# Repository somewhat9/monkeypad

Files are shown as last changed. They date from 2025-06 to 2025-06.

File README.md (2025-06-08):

# Monkeypad
Monkeypad is a macropad with 9 switches, an OLED screen and a rotary encoder.

*Completely designed by [@somewhat9](github.com/somewhat9).*  
  
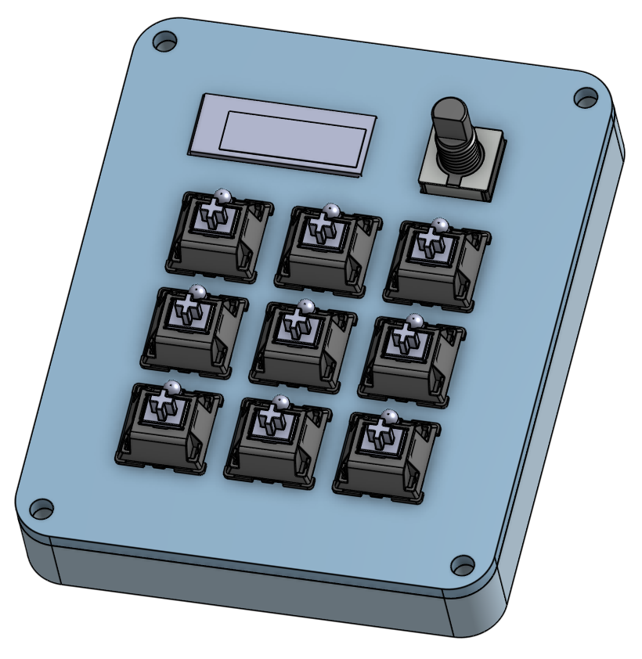
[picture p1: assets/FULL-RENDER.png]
Monkeypad


## Features:
- 128x32 OLED Display
- EC11 Rotary Encoder
- 9 Keys
- 3D Printed Case
- QMK Firmware

### Schematic
Used [KiCAD](https://www.kicad.org/), an open source EDA software, to create the schematic and design the PCB.  

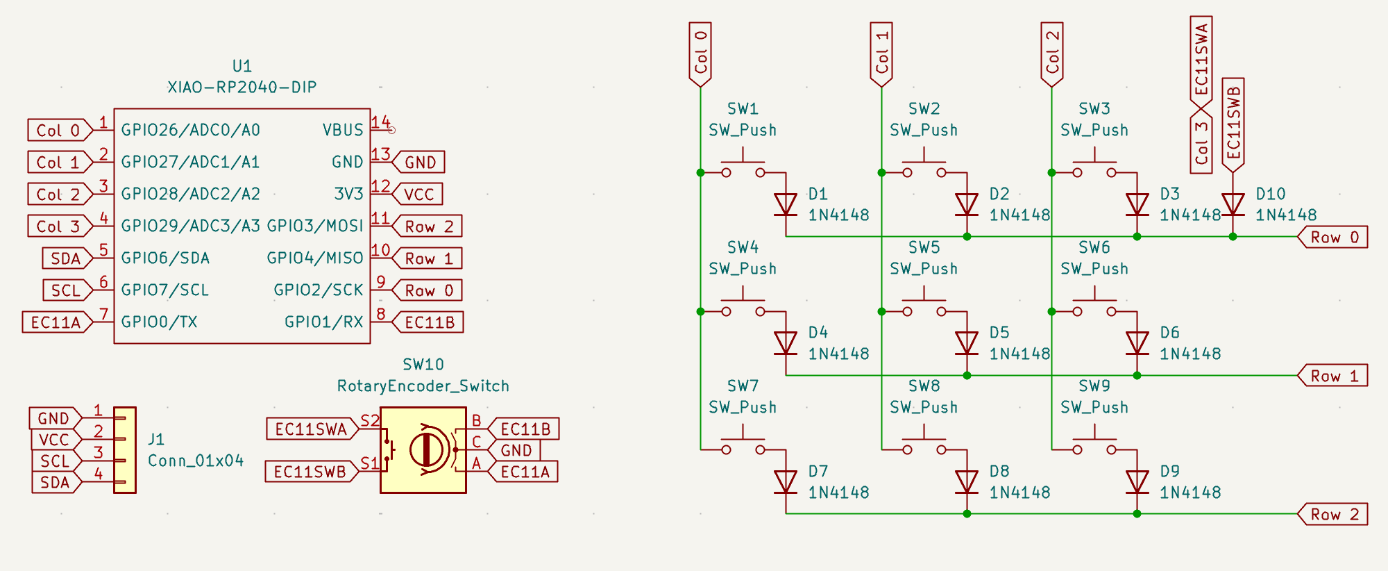
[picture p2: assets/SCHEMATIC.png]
Schematic


### PCB
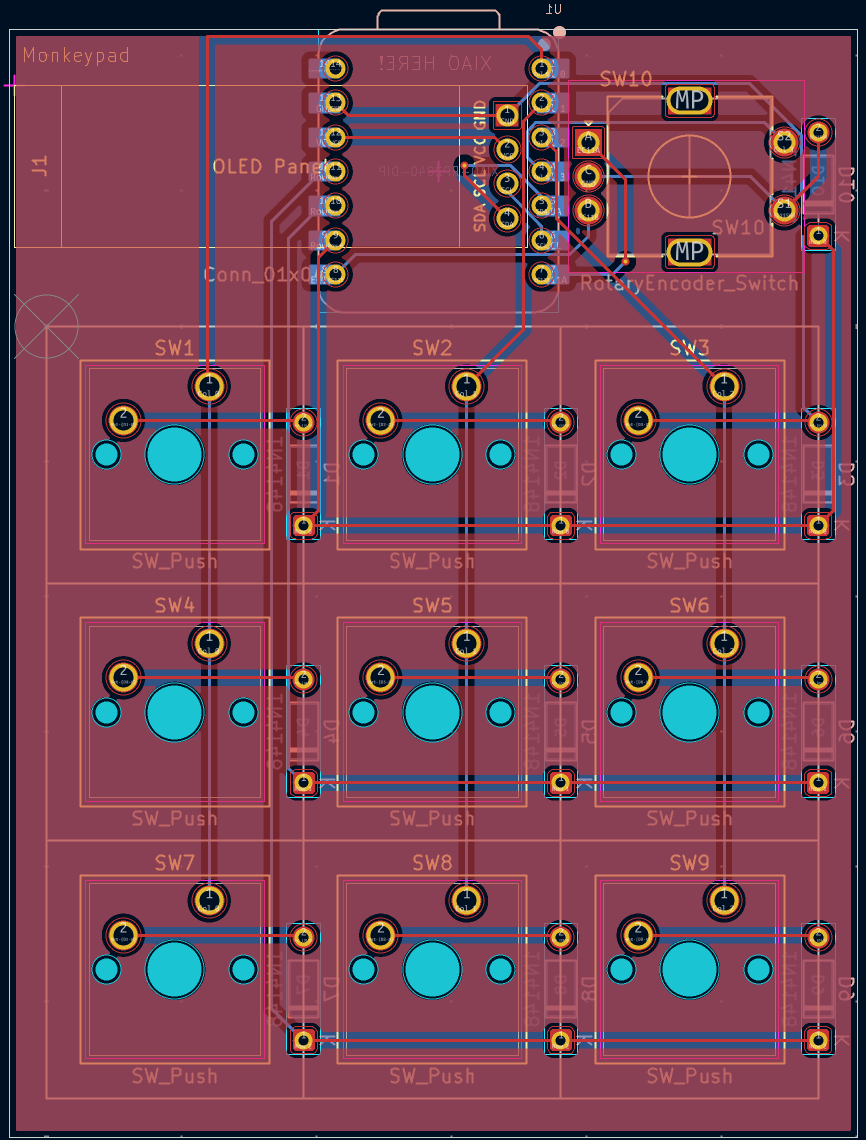
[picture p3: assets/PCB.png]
PCB


### Case
Utilized [Onshape](https://www.onshape.com/en/), a 3D modeling CAD software, to design the 3D models for the case.  

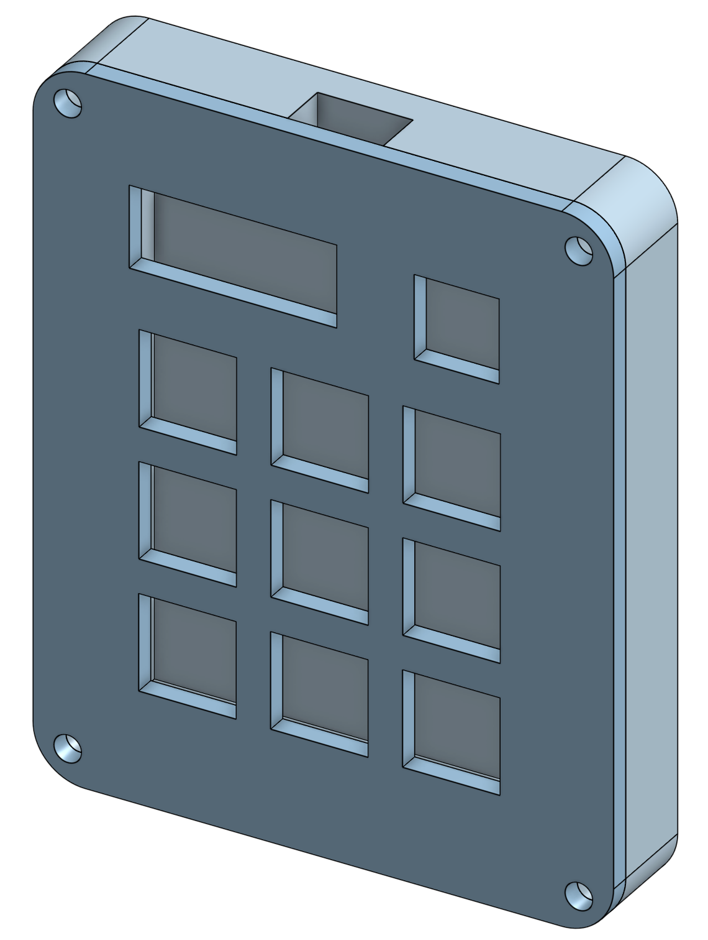
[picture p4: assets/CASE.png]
Case


### Firmware
The firmware for this macropad was built using the [QMK](https://qmk.fm/) project.
The open-source repository can be found [here](https://github.com/qmk/qmk_firmware).

## BOM:
- 9x Cherry MX Switches
- 1x EC11 Rotary Encoder
- 1x 128x32 OLED Display
- 1x XIAO RP2040
- 9x Blank DSA Keycaps (White)
- 4x M3x16mm Screws
- 4x M3x5mx4mm Heatset Inserts
- 1x 3D Printed Case

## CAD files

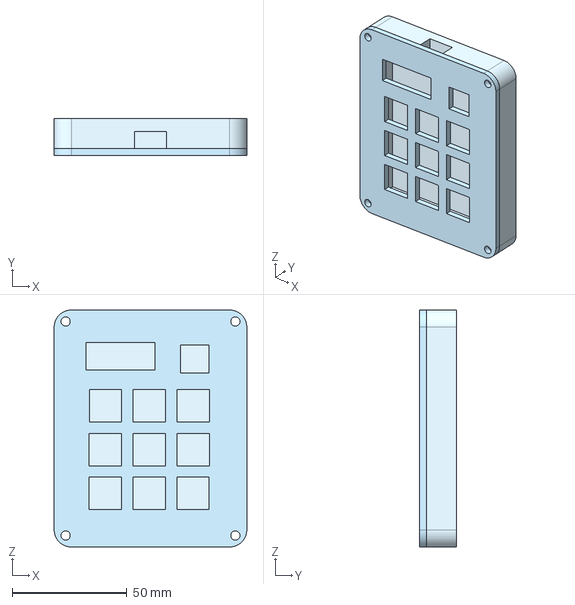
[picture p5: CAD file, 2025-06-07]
cad/monkeypad.step
83.8 x 16.0 x 103.1 mm

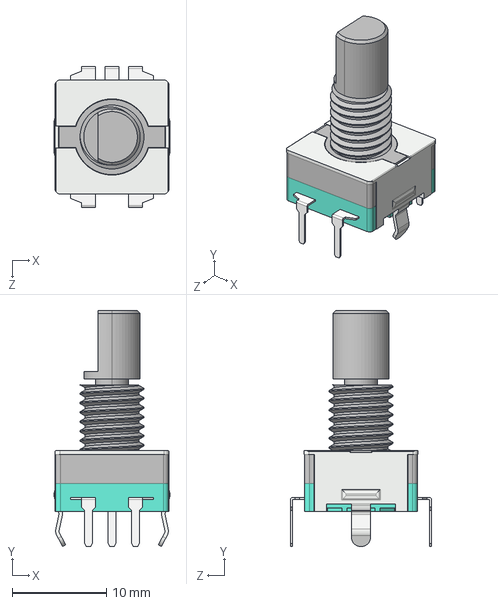
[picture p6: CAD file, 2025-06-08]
pcb/models/ENCODER.step
12.3 x 25.1 x 15.0 mm

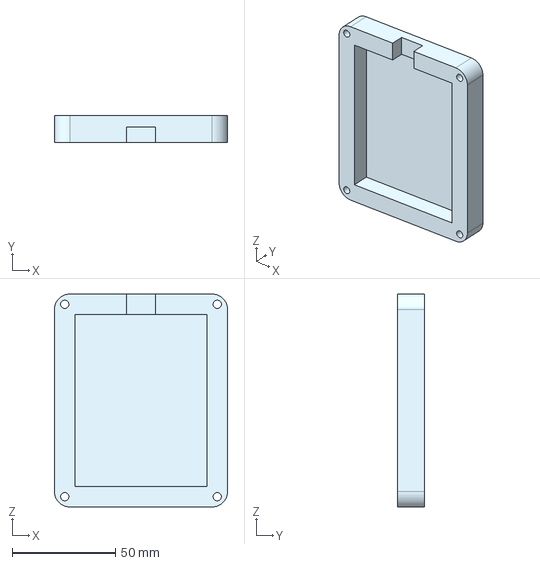
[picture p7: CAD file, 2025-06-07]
production/base.step
83.8 x 13.0 x 103.1 mm

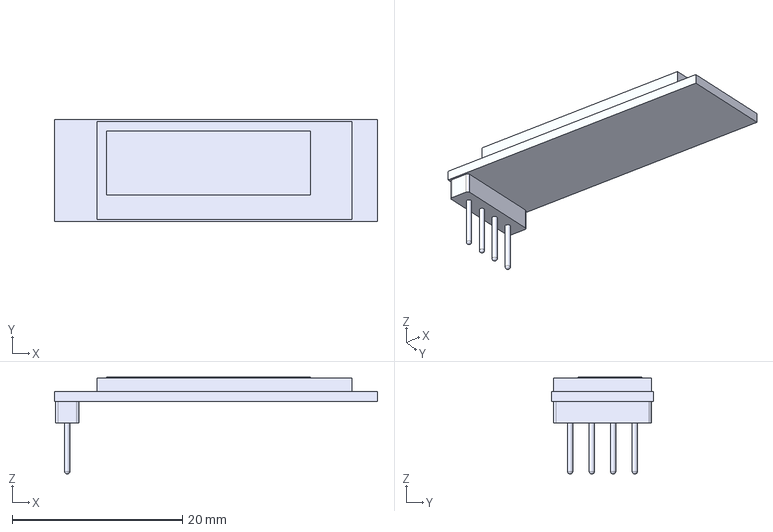
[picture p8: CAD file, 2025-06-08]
pcb/models/128x32-OLED.step
38.0 x 12.0 x 11.4 mm

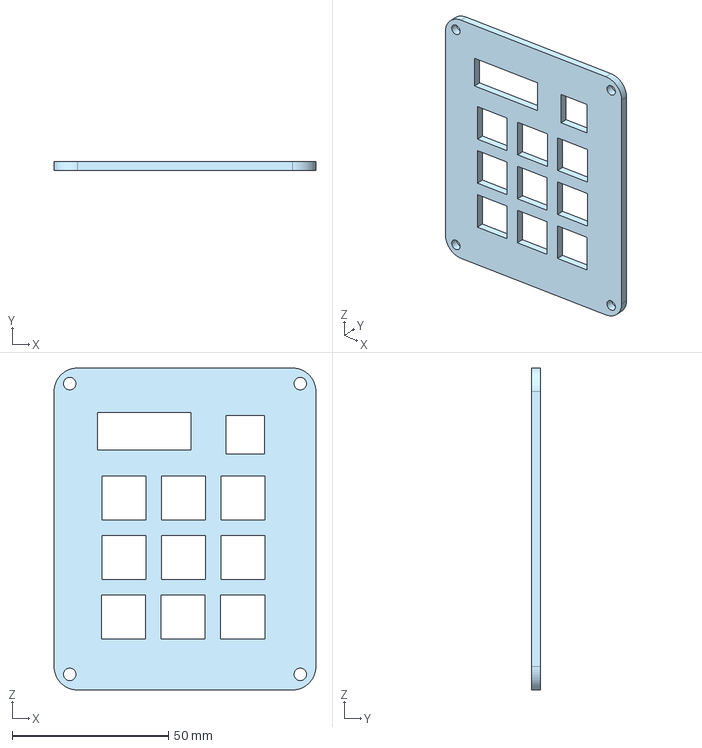
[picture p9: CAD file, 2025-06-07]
production/top.step
83.8 x 3.00 x 103.1 mm

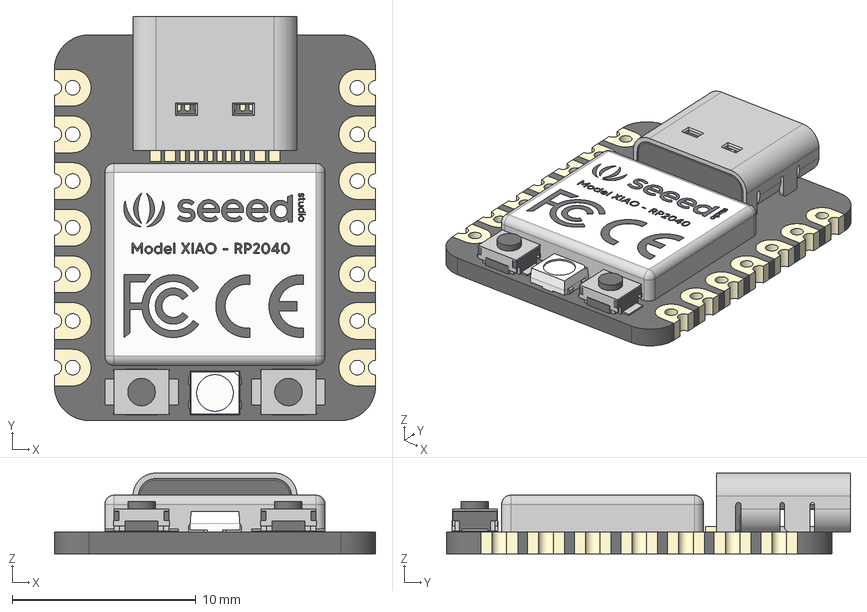
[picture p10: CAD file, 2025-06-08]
pcb/models/XIAO-RP2040.step
17.5 x 22.0 x 4.40 mm
type-c v2
smd_button v3
DOUT
DIN
VSS
VDD
smd_button v3(Mirror)

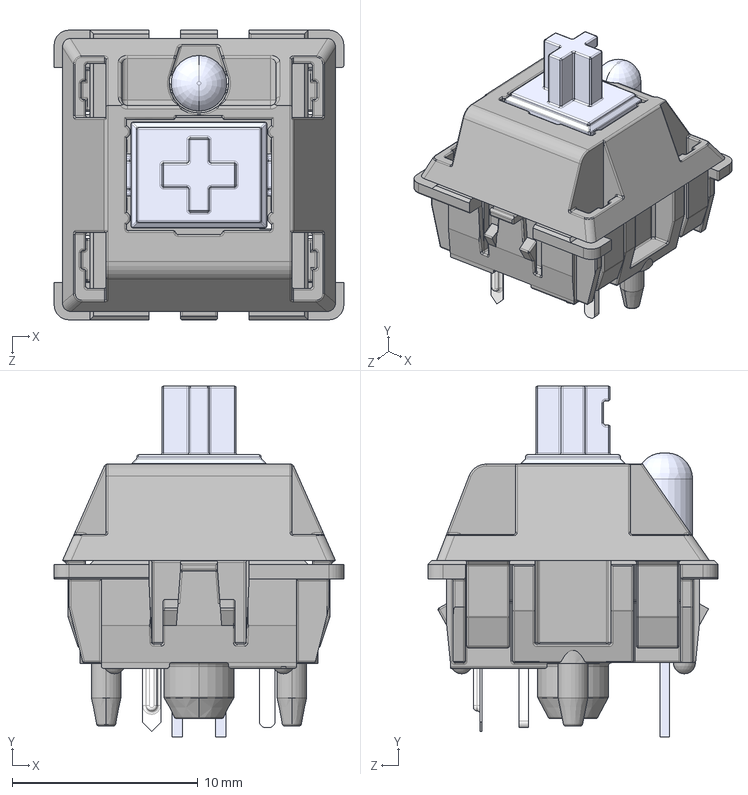
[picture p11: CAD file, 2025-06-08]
pcb/models/MX.step
15.6 x 18.9 x 15.6 mm
MX 轴 按键′_ü___¨1
MX 轴 轴体áì_¨￠¨__
MX粣 拸簽LEDLEDLED
MX轴 轴体 底部 μ×2__默认_á2____è_
针脚___默认__è_

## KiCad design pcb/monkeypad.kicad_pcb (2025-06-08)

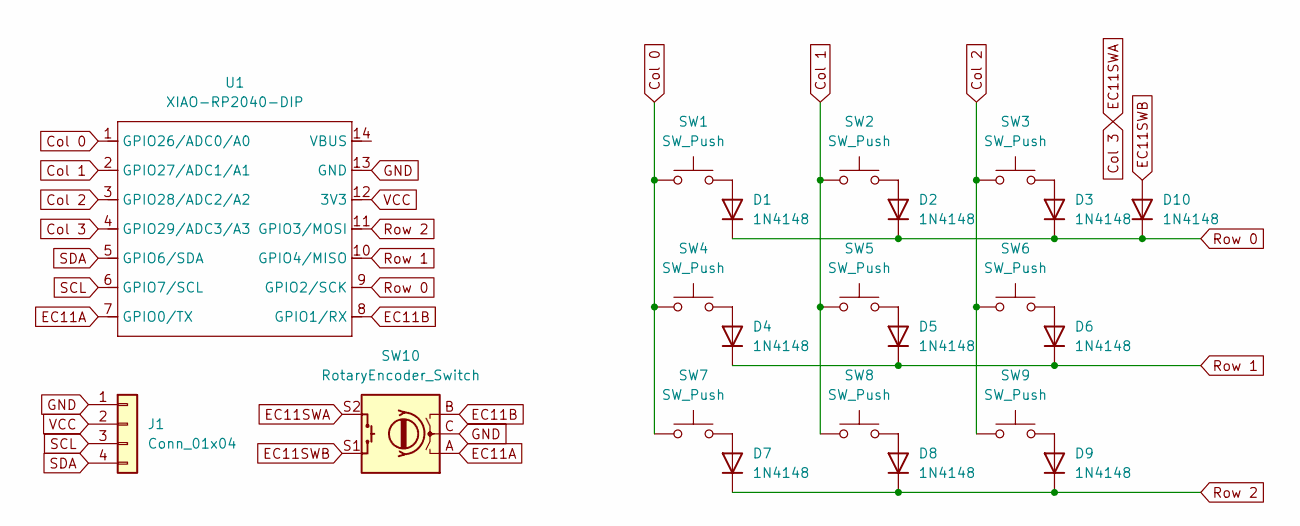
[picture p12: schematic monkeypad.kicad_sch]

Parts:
D1, D2, D3, D4, D5, D6, D7, D8, D9, D10: 1N4148; D_DO-35_SOD27_P7.62mm_Horizontal
J1: Conn_01x04; SSD1306-0.91-OLED-4pin-128x32
SW1, SW2, SW3, SW4, SW5, SW6, SW7, SW8, SW9: SW_Push; SW_Cherry_MX_1.00u_PCB
SW10: RotaryEncoder_Switch; RotaryEncoder_Alps_EC11E-Switch_Vertical_H20mm
U1: XIAO-RP2040-DIP

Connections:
Col 0: SW1.1, SW4.1, SW7.1, U1.1 (GPIO26/ADC0/A0)
Col 1: SW2.1, SW5.1, SW8.1, U1.2 (GPIO27/ADC1/A1)
Col 2: SW3.1, SW6.1, SW9.1, U1.3 (GPIO28/ADC2/A2)
Col 3: SW10.S2, U1.4 (GPIO29/ADC3/A3)
EC11A: SW10.A, U1.7 (GPIO0/TX)
EC11B: SW10.B, U1.8 (GPIO1/RX)
EC11SWB: D10.2 (A), SW10.S1
GND: J1.1, SW10.C, U1.13 (GND)
unnamed: D1.2 (A), SW1.2
unnamed: D2.2 (A), SW2.2
unnamed: D3.2 (A), SW3.2
unnamed: D4.2 (A), SW4.2
unnamed: D5.2 (A), SW5.2
unnamed: D6.2 (A), SW6.2
unnamed: D7.2 (A), SW7.2
unnamed: D8.2 (A), SW8.2
unnamed: D9.2 (A), SW9.2
Row 0: D1.1 (K), D2.1 (K), D3.1 (K), D10.1 (K), U1.9 (GPIO2/SCK)
Row 1: D4.1 (K), D5.1 (K), D6.1 (K), U1.10 (GPIO4/MISO)
Row 2: D7.1 (K), D8.1 (K), D9.1 (K), U1.11 (GPIO3/MOSI)
SCL: J1.3, U1.6 (GPIO7/SCL)
SDA: J1.4, U1.5 (GPIO6/SDA)
VCC: J1.2, U1.12 (3V3)

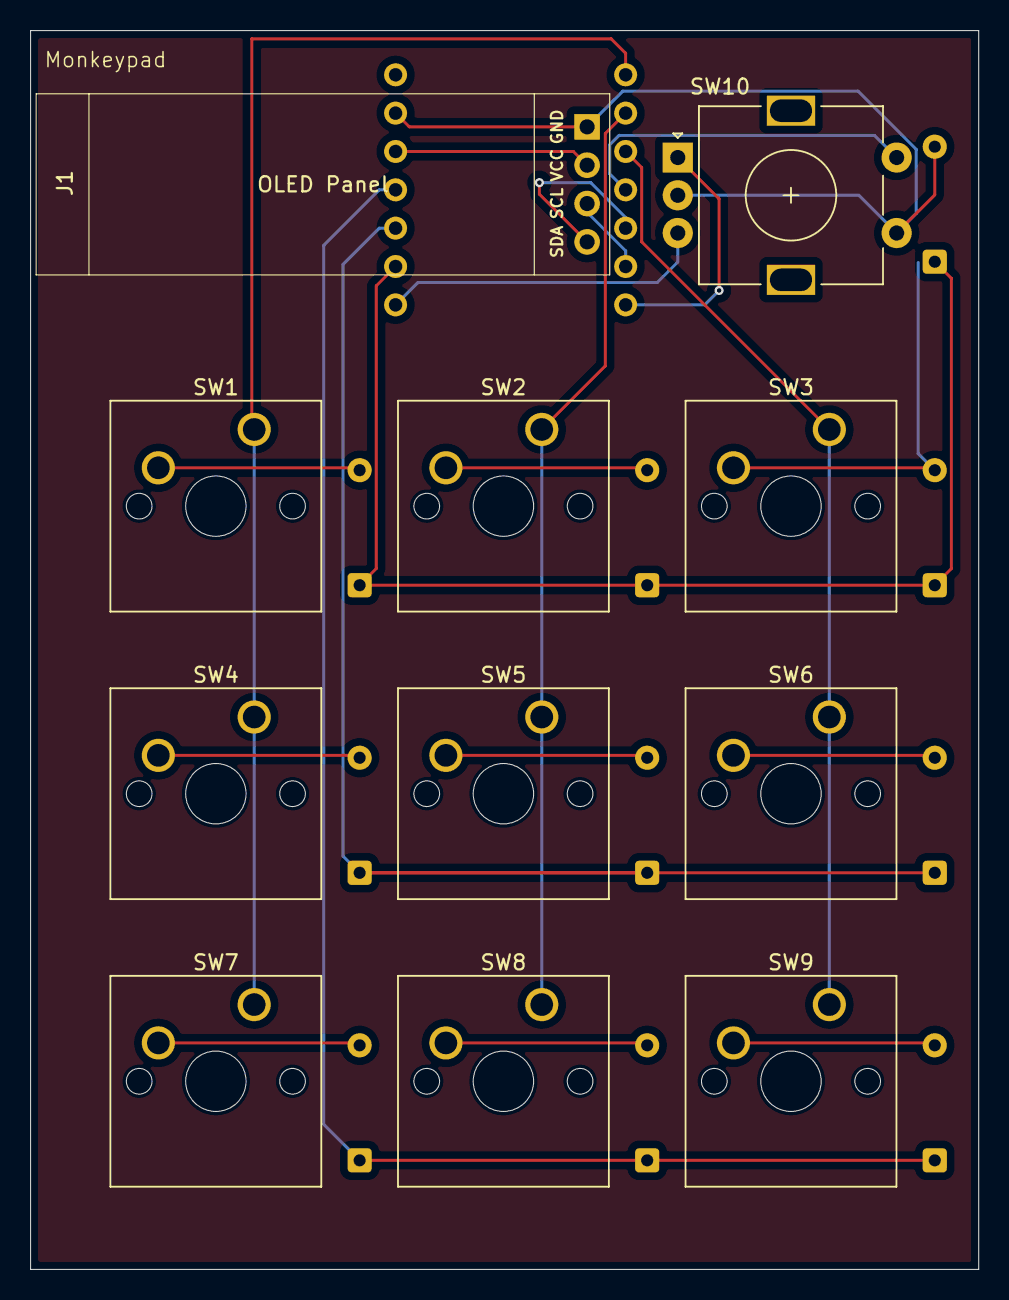
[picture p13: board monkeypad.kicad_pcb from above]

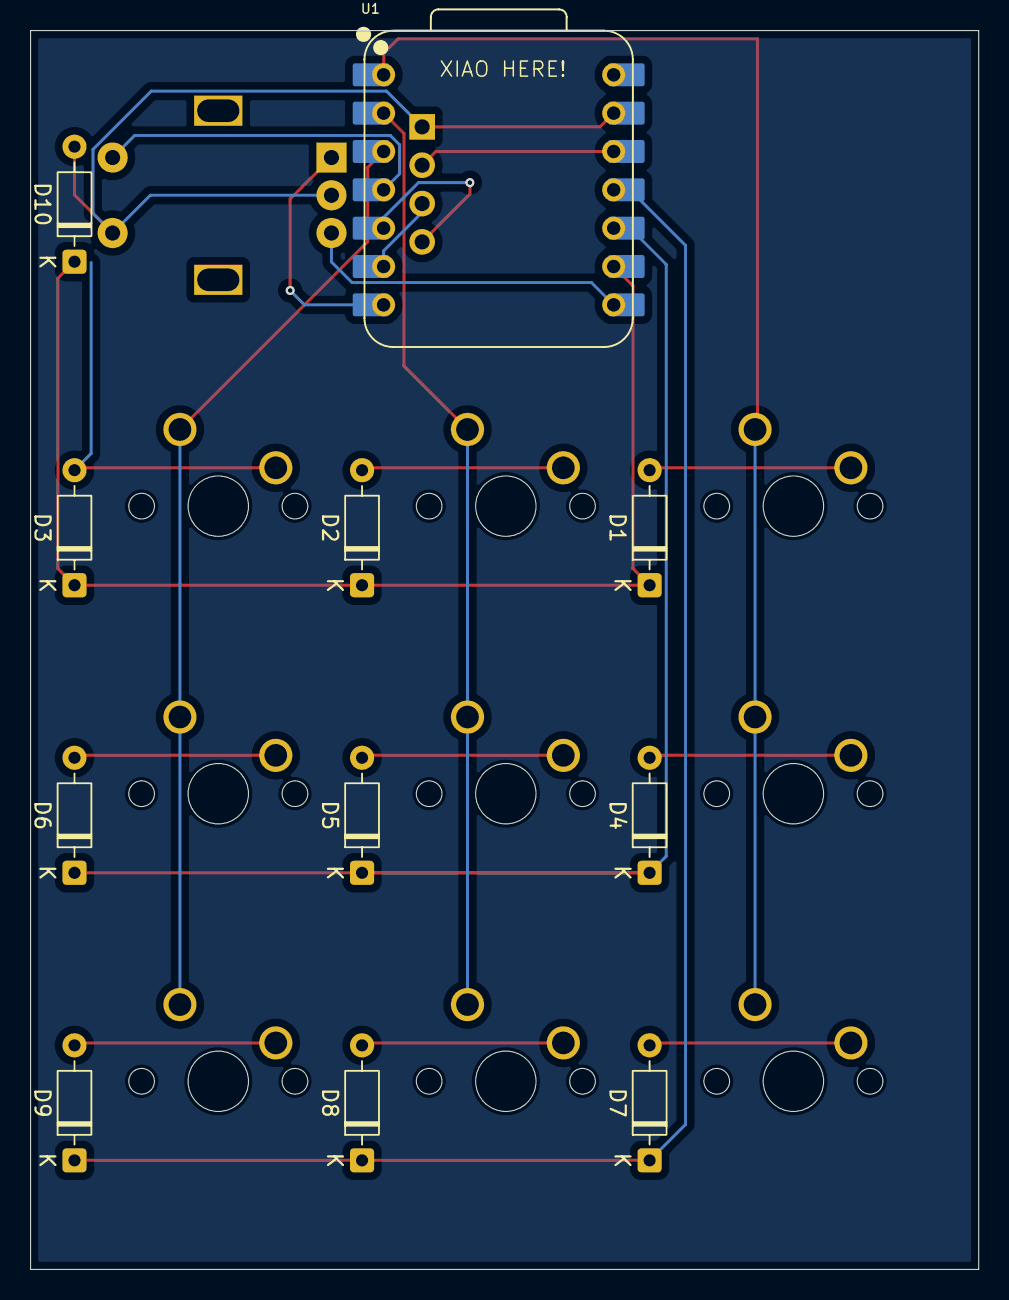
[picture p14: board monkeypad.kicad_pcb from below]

Board: 2 copper layers, 62.8 x 82.1 mm, 22 parts (11 on the bottom side), 23 nets.

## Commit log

2025-06-07 Add CAD, PCB, Firmware
    Added all the CAD, PCB and firmware files for the macropad.
    [base.step, monkeypad.kicad_pcb, monkeypad.kicad_sch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]
2025-06-08 Added 3D Models, Assets, README
    Added 3D models for the PCB, image assets, and a README.
    [128x32-OLED.step, ENCODER.step, MX.step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]
2025-06-08 Fixed Schematic Asset
